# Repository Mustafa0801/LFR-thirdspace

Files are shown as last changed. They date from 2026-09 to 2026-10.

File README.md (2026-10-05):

# LFR-thirdspace
Line following robot project for HackClub YSWS thirdspace, uses 2 motors and an array of 5 sensors

PLEASE NOTE: THE PLAYABLES FOR WEEK 1 AND 2 WERE BUGGED SO I HAVE FIXED THEM NOW, THE LINKS IN THE SUBMISSION DONT WORK SO PLEASE FIND THE DEMOS FOR WEEK 1 AND 2 IN THE PLAYABLES FOLDER

## WEEK 1
It is very important to note that this week we did not really have any of the hardware components for the robot ready e.g motors, sensors, e.t.c.
The only thing we had was the Arduino UNO; it wasn't possible to properly test any of the code so some things in the code have kinda been eyeballed.
Because of that, most of the code at the moment is not finalised and rather the code is more like a first draft.  
For the cad designs, there were a lot of linux glitches, along with save files being corrupted which meant things had to be redone.
The basic things are done but the design will be finalized before 3D printing

## WEEK 2
Had a lot of technical difficulties this week as well in obtaining the parts, and even after we got the parts, some were faulty. 
Also were unable to get chassis printed so only made a very rough version of the robot.  
Due to lack of time we weren't able to test it enough so it has many issues, only motors were tested which aren't working as intended.
However it is probably issue with the hardware rather than the code.

## WEEK 3
Hoped to finish the project this week but once again faced some technical difficulties, did everything that we needed to do however some components seem to be faulty due to which the robot is unable to move. Unfortunately we will have to continue it to the next week. it's very disappointing but it feels there is nothing we can do to make it work.

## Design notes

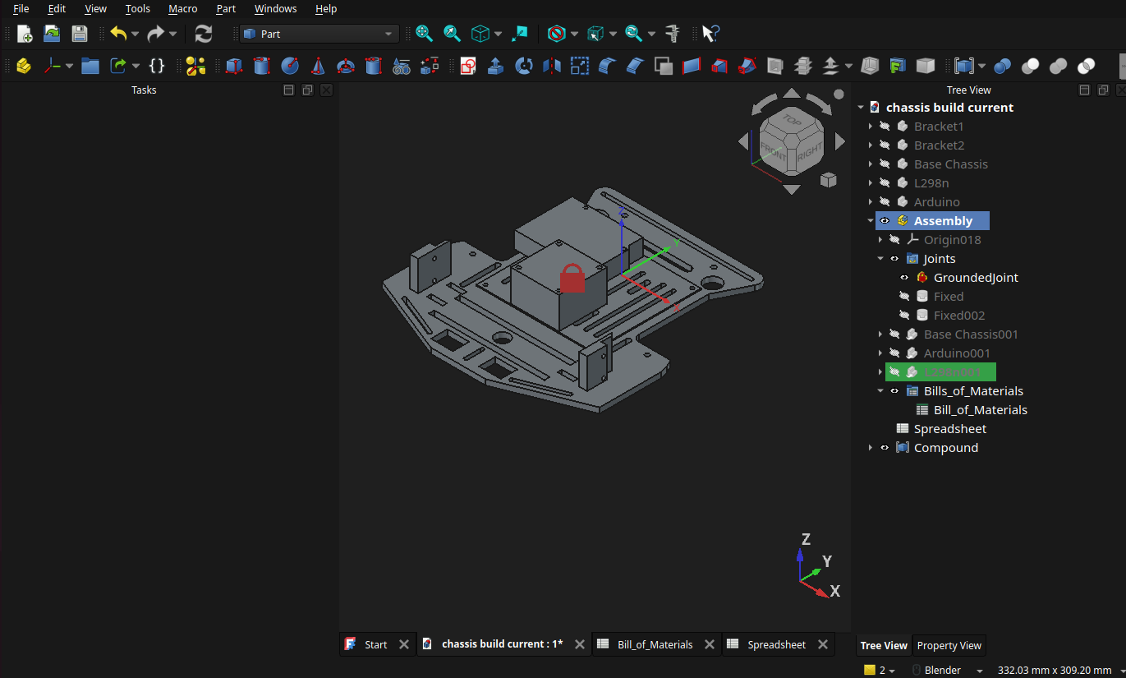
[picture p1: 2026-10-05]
final ship/Screenshot from 2026-10-04 20-36-11.png

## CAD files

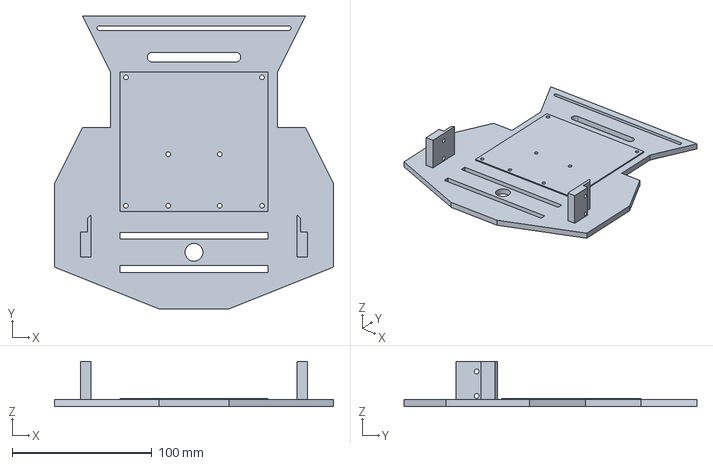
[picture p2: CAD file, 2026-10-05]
final ship/chassis build current with l298n holes and full chassis stuff including 2 chamfer.FCStd
200.0 x 210.0 x 32.5 mm

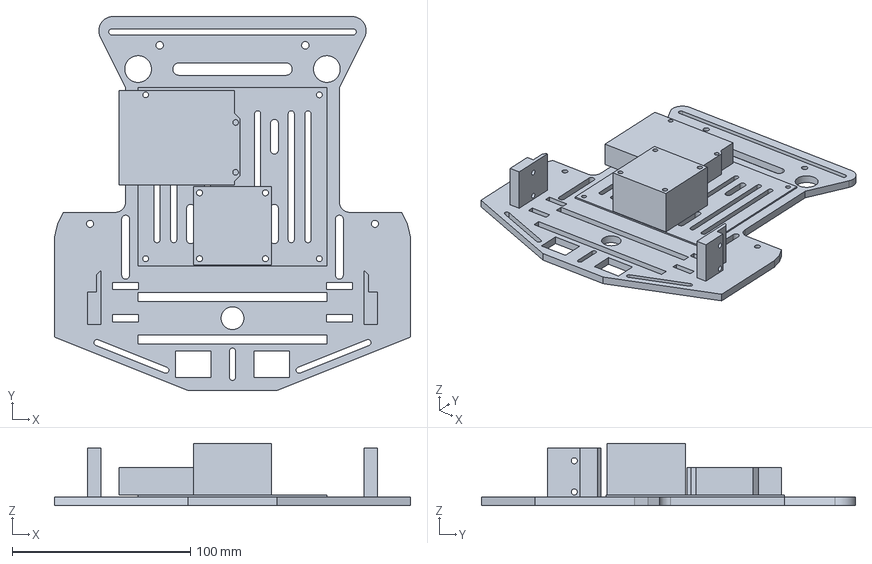
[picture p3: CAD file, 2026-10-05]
final ship/CHASSIS BUILD LAST COMPLETE SENT FOR 3d PR.FCStd
200.0 x 210.0 x 35.0 mm

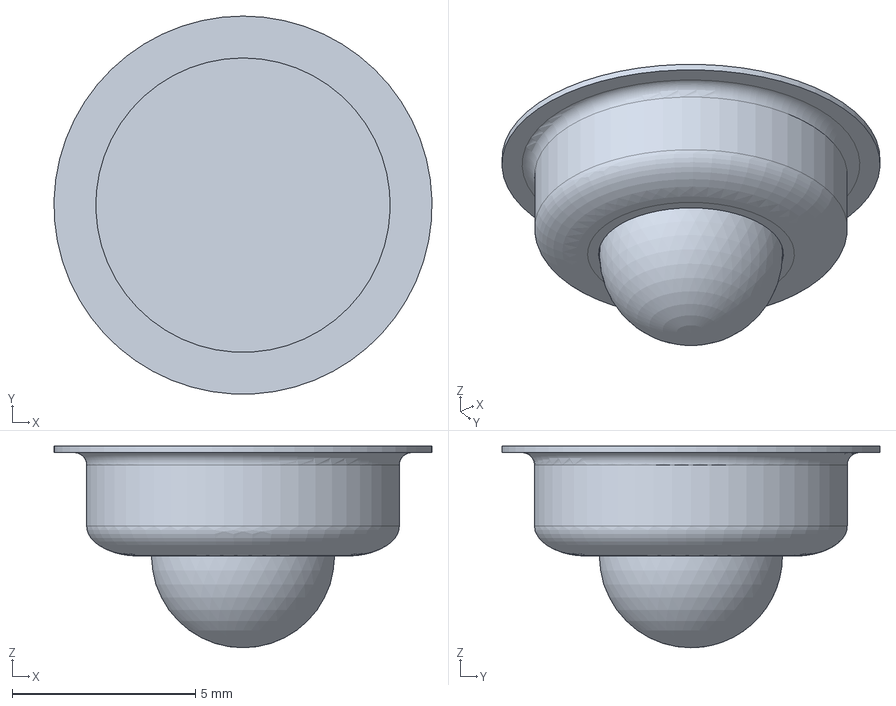
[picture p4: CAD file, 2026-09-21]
CAD files/Final Assembly assorted.FCStd
10.3 x 10.3 x 5.50 mm

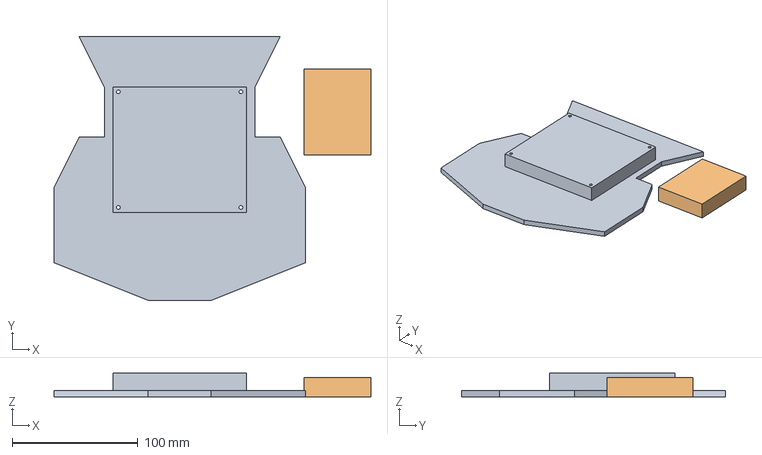
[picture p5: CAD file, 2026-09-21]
CAD files/Unnamed2.FCStd
252.3 x 210.0 x 19.0 mm
Base Chassis
Arduino Dimensions

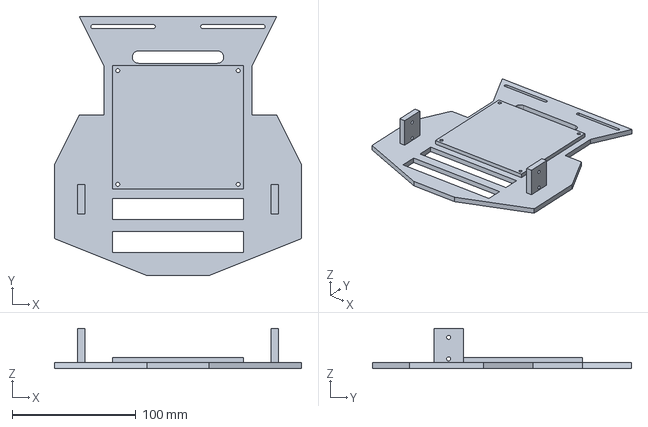
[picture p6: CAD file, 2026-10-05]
final ship/chassis build with hole for wires final.FCStd
200.0 x 210.0 x 32.5 mm

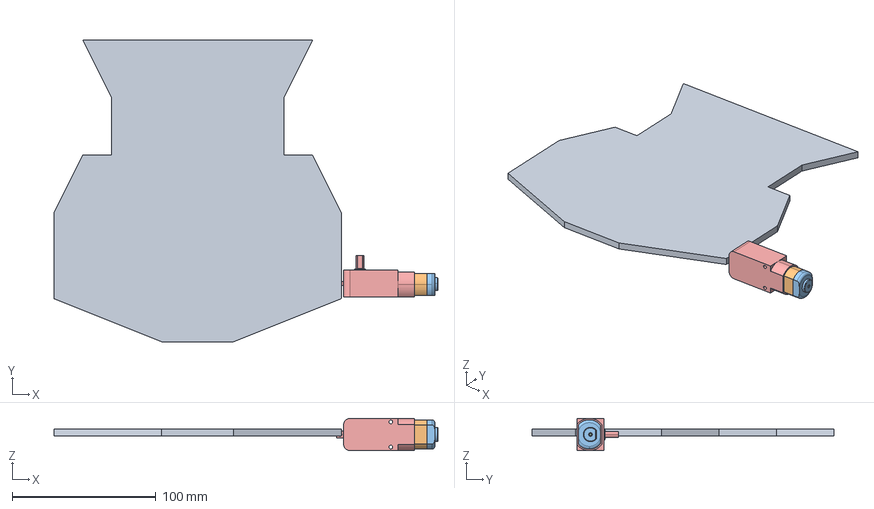
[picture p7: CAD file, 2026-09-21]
CAD files/Base Model One Chassis.FCStd
267.3 x 210.0 x 22.5 mm
Base Chassis
Motor con reductor
Motor con reductor001
Motor con reductor002
Motor con reductor003

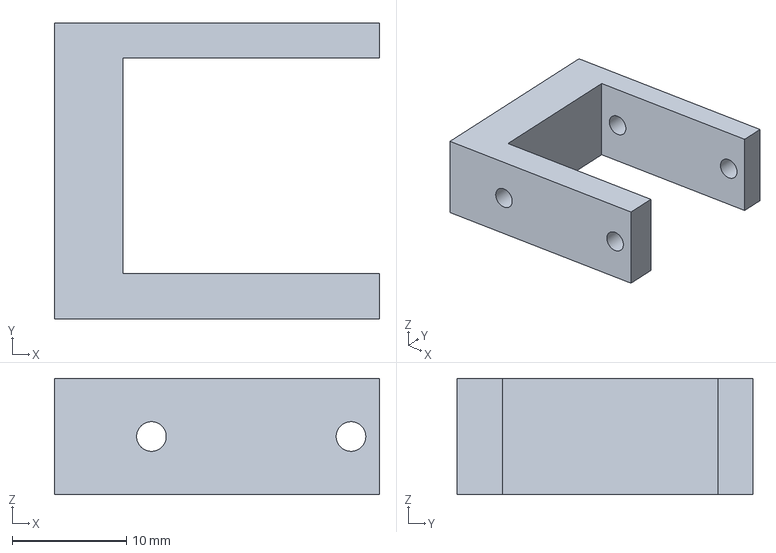
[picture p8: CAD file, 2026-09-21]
CAD files/Bracket for Motor.FCStd
28.5 x 26.0 x 10.2 mm

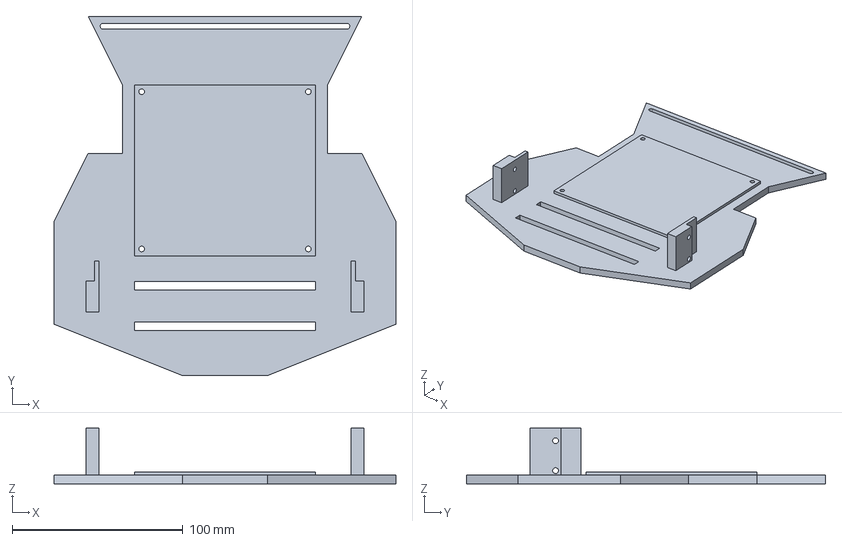
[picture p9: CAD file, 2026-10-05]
final ship/chassis build october 3 proper sensor mount hole 3.35 mm.FCStd
200.0 x 210.0 x 32.5 mm

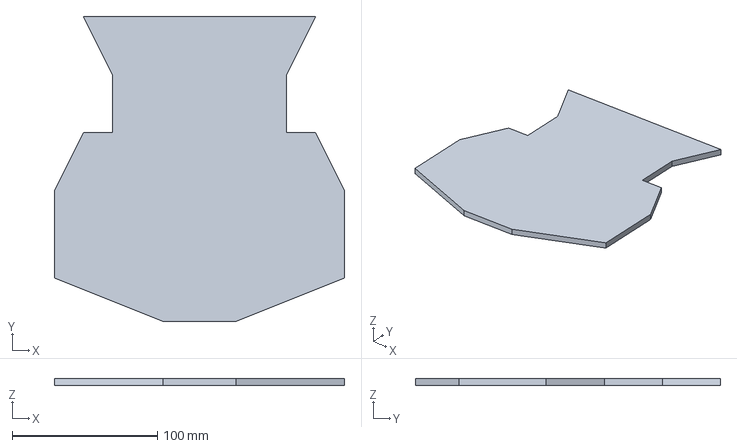
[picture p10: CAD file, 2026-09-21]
CAD files/Base Model One Chassis (Copy).FCStd
200.0 x 210.0 x 5.00 mm

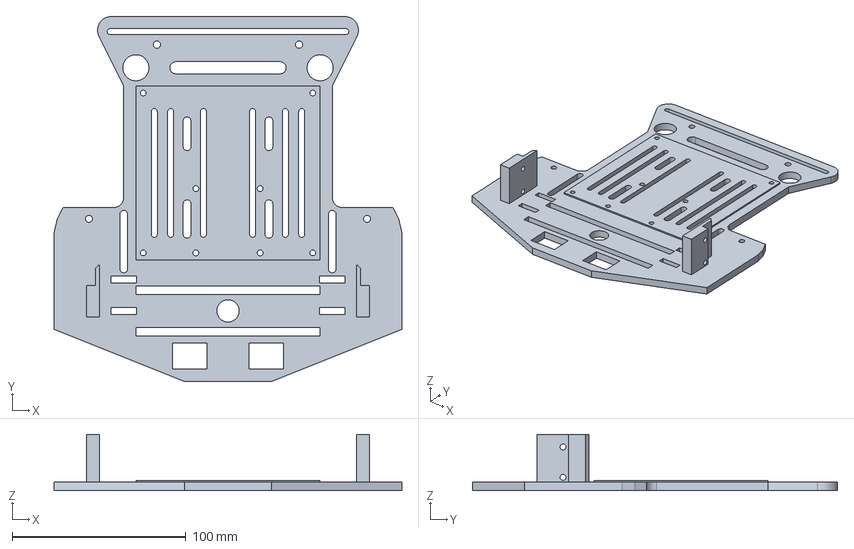
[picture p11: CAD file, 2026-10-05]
final ship/chassis build october 4 with many holes except bottom sensors.FCStd
200.0 x 210.0 x 32.5 mm

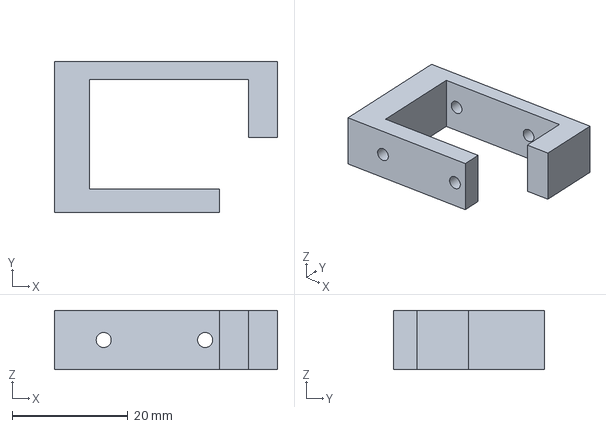
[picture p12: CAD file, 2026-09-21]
CAD files/Bracket for Motor (Copy).FCStd
38.5 x 26.0 x 10.2 mm

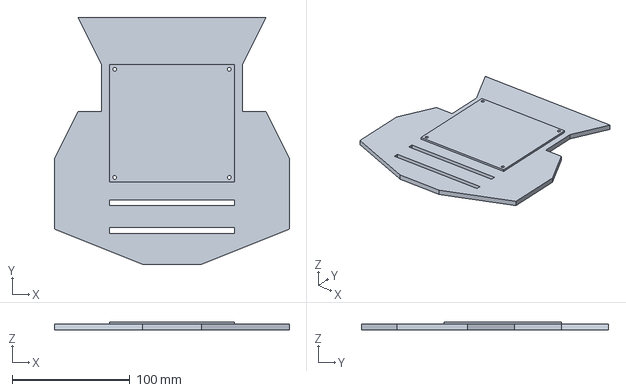
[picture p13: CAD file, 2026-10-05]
final ship/chassis build redone with smaller holes on account of the motor driver.FCStd
200.0 x 210.0 x 7.00 mm

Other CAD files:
CAD files/Assembly retry.FCStd
CAD files/Final Assembly assorted (Copy 2).FCStd
CAD files/Final Assembly assorted (Copy 3).FCStd
CAD files/Final Assembly assorted (Copy).FCStd
CAD files/Final Assembly assorted (Copy 4).FCStd
CAD files/fusionassemblywithball.FCStd
CAD files/Assorted Assets (Copy 3).FCStd
CAD files/Assorted Assets (Copy).FCStd
CAD files/Assorted fusion.FCStd
CAD files/FINAL bracket for motor.FCStd
CAD files/Fused Motor.FCStd
CAD files/Raised platform for arduino.FCStd
CAD files/Unnamed.FCStd
CAD files/fusion1.FCStd
CAD files/mule.FCStd
CAD files/mule2.FCStd
CAD files/sensor hanging mounting bracket.FCStd
final ship/chassis build current.FCStd
final ship/chassis build october 3 first space-saving cut.FCStd
final ship/chassis build october 3 proper bracket hole with indent.FCStd
final ship/chassis build october 3 with proper sensor mount and hole for cables.FCStd

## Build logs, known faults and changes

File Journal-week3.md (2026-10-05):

# Week 3 Hardware Journal
## Mustafa0801
MONDAY --- First I tested motors more and found that the issue was related to power, so I connected more batteries.  
TUESDAY --- Then tested the sensors a bit, found that they need to be quite low to the ground to detect the line.  
FRIDAY --- Wired the buck to the robot, then tested the draft1 of full code on the track, the movement was a bit jittery and the robot was getting stuck.  
SATURDAY --- Moved the track to the floor instead of the bed and tested again, robot was working fine (aside from the movement being a bit snappy)
however the track itself was still causing issues.  
SUNDAY --- Remade the track on the floor, then tested robot a bit on it. Now the issue wasn't the track rather the robot's structure causing it to get stuck.
Then assembled 3D printed chassis and rewired everything, however the robot was still getting stuck on the ground. It would work fine in the air but on the ground the wheels would just not move, which seemed to be a power issue. Even at max speed the robot couldn't move unless it was constantly pushed a little here and there. Could also be due to faulty motors which is something we may not be able to fix now.
    
WhatsApp Image 2026-10-05 at 7 28 50 AM
WhatsApp Image 2026-10-05 at 7 28 49 AM
WhatsApp Image 2026-10-05 at 7 28 51 AM

## Muhammad
Cad journal:
Main things that I did were to make sure all my mounts were proper. It took quite some time and I had to redo them twice or thrice because i realised that either the hole sizes were weird or that my sketch wasnt truly editable or changable later, and so for the sake of making possible edits i redid many sketches on the base plate
I also calculated the volume requires to 3d print the base chassis in the BOM, ans generally just validated my design
I also added a small modular plate thing on the padded area at the top and added mounting holes and weights to the arduino and l298n. Freecad crashed and my files corrupted twice so I had to redo them again. Lastly i imported my model to make sure it sliced properly in the prussa slicer. It did, so I tried to find the center of mass with the weights so I couls find the optimum place to put in the "castor wheel"  (but it didnt end up working properly so I just eyeballed it and called it a day)

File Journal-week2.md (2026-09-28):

# Week 2 Hardware Journal 
## Mustafa0801
Created a track for the LFR, by putting black tape on a white sheet. (took about 2 hours)  
Then tested the robot with the motor code, adjusted some wiring and components on the robot and updated code accordingly. (about 5 hours)
However motors still didnt work as intended, most times when both should move only 1 moves or neither move, probably a power issue.  
  \
WhatsApp Image 2026-09-28 at 6 55 17 AM
WhatsApp Image 2026-09-28 at 6 55 18 AM
WhatsApp Image 2026-09-28 at 6 56 11 AM

## Muhammad
Took a lot of time wiring the robot, motors kept falling off so they had to be re-adjusted. Lengths were measured for the base.

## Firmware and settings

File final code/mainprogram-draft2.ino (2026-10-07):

// INCORPORATNG EVERYTHING INCLUDING PID, THIS WILL PROBABLY BE FINAL CODE (AFTER TESTING)

// pin numbers for motors and wheel servos

#define leftMotor 5
#define rightMotor 3
#define lf 2    // left forward servo
#define rf 7    // right forward servo
#define lb 4    // left back servo
#define rb 6    // right back servo

// pin numbers for sensor array

#define irL2 8   // left most
#define irL1 9  // left of middle
#define irM 10    // middle
#define irR1 11    // right of middle
#define irR2 12    // right most

float error;
float previousError = 0;    
float integral = 0;

float baseSpeed = 200.0;  
float leftSpeed;
float rightSpeed;

unsigned long currentTime;    // used to calculate delta time
unsigned long lastTime;

float Kp = 20.0;
float Ki = 0.5;    // constants used to calculate PID (still need to be adjusted) 
float Kd = 5.0;

void setup() {
  pinMode(leftMotor, OUTPUT);
  pinMode(rightMotor, OUTPUT);
  pinMode(lf, OUTPUT);
  pinMode(rf, OUTPUT);
  pinMode(lb, OUTPUT);
  pinMode(rb, OUTPUT);

  pinMode(irL2, INPUT);
  pinMode(irL1, INPUT);
  pinMode(irM, INPUT);
  pinMode(irR1, INPUT);
  pinMode(irR2, INPUT);

  lastTime = micros();
  Serial.begin(9600);
}

void loop() {
  error = ReadSensors();
  float outputPID = CalculatePID(error);

  Serial.println();

  leftSpeed = baseSpeed - outputPID;
  rightSpeed = baseSpeed + outputPID;  // speed is adjusted according to PID to allow robot to move smoothly and accurately

  // maximum and minimum thresholds for speed, since we can only analogWrite values between 0-255 inclusive
  if (leftSpeed > 255.0){
    leftSpeed = 255.0;
  }
  else if (leftSpeed < 0){
    leftSpeed = 0;
  }
  if (rightSpeed > 255.0){
    rightSpeed = 255.0;
  }
  else if (rightSpeed < 0){
    rightSpeed = 0;
  }

  leftSpeed = round(leftSpeed);     // converting speeds from float to int since the movement functions need integer value for speed
  rightSpeed = round(rightSpeed);
  Serial.print(" | left speed: "+String(leftSpeed)+" right speed: "+String(rightSpeed));

  Forward(leftSpeed, rightSpeed);  // the direction will be automatically changed by the varying left and right speeds

  Serial.println();   // going to next line
}

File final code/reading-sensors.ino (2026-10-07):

//  FUNCTION FOR READING SENSORS AND CALCULATING ERROR FROM LINE

float ReadSensors(){
  int _readingL2 = !digitalRead(irL2);
  int _readingL1 = !digitalRead(irL1);
  int _readingM = !digitalRead(irM);    // reading all sensors, 
  int _readingR1 = !digitalRead(irR1);  // ! inverts the values since the formula for calculating error assumes that a sensor detecting the line gives value 1
  int _readingR2 = !digitalRead(irR2);

  Serial.print("Readings: "+String(_readingL2)+" "+String(_readingL1)+" "+String(_readingM)+" "+String(_readingR1)+" "+String(_readingR2)); // prints readings in a line e.g  0 1 0 0 0

  if ((_readingL2 + _readingL1 +_readingM + _readingR1 + _readingR2) == 0){ // prevents dividing by zero in weight position formula
    return previousError;
  }

  // weighted position algorithm to calculate error

  float _currentPosition = (_readingL2*0 + _readingL1*1 + _readingM*2 + _readingR1*3 + _readingR2*4) / (_readingL2 + _readingL1 + _readingM + _readingR1 + _readingR2);
  float _normalPosition = 2.0;
  float _error = _normalPosition - _currentPosition;  // negative error means robot is right side of line (needs to move left), 
                                                      // positive error means robot is left side of line (needs to move right)

  // value of _currentPosition will be between 0 and 4.0 inclusive, hence value of _error will be between -2.0 and 2.0 inclusive
                              
  Serial.print(" | error: "+String(_error));
  return _error;
}

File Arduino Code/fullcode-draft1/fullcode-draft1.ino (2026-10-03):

//  COMBINING PREVIOUS WRITTEN CODE INTO ONE FILE TO GET A DRAFT OF THE COLLECTIVE CODE

#define leftMotor 5
#define rightMotor 3
#define lf 2  // declaring pin numbers for motors
#define lb 4
#define rf 7
#define rb 6

#define irL2 8 // declaring pin numbers for sensor array
#define irL1 9
#define irM 10
#define irR1 11
#define irR2 12

int leftSpeed = 200;  // placeholder values for speeds
int rightSpeed = 200;
int linePos;

void setup() {
  pinMode(leftMotor, OUTPUT);
  pinMode(rightMotor, OUTPUT);
  pinMode(lf, OUTPUT);
  pinMode(lb, OUTPUT);    
  pinMode(rf, OUTPUT);
  pinMode(rb, OUTPUT);

  pinMode(irL2, INPUT);
  pinMode(irL1, INPUT);
  pinMode(irM, INPUT);
  pinMode(irR1, INPUT);
  pinMode(irR2, INPUT);

  Serial.begin(9600);
}

void loop() {
  linePos = ReadSensors();  // reads all sensors, prints in serial, and stores line position

  switch (linePos){     // checks line position to decide movement of robot
    case -4:            
      leftRotate(leftSpeed, rightSpeed);  // if line is far left then robot needs to turn sharply left
      break;
    case -2:
      leftTurn(leftSpeed, rightSpeed);      // line is slightly left so robot needs to move left slightly
      break;
    case 0:
      forward(leftSpeed, rightSpeed);   // line is infront so robot needs to move forward
      break;
    case 2:
      rightTurn(leftSpeed, rightSpeed);     // line slightly right, robot needs to move slightly right
      break;
    case 4:
      rightRotate(leftSpeed, rightSpeed); // line far right, robot needs to turn sharply right
      break;
  }

  Serial.println();   // goes to next line in serial
}

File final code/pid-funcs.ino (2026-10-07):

// FUNCTIONS FOR CALCULATING DELTA TIME AND CALCULATING PID

float CalculateDeltaTime(){
  currentTime = micros();   // total time since start
  float _dt = (currentTime - lastTime) / 1000000.0;   // difference in time between each loop, converted to seconds
  lastTime = currentTime;   // last time updated for next loop
  Serial.print(" | dt: "+String(_dt));

  return _dt; 
}

float CalculatePID(float _error){
  float deltaTime = CalculateDeltaTime();
  float _output;

  if (deltaTime <= 0){  // to prevent dividing by zero
    _output = 0;
  }
  else{
    integral = integral + (_error * deltaTime);   // sums errors over time
    float _derivative = (_error - previousError) / deltaTime;   // rate of change of errors

    previousError = _error;   // previous error updated for next loop

    _output = (Kp * _error) + (Ki * integral) + (Kd * _derivative); // calculating PID output

    // limits output to prevent integral windup, NOTE: speeds can still exceed max and min values with this so they also need to be limited seperately
    if (_output > 255.0){
      _output = 255.0;
      integral = integral - (_error * deltaTime);  // prevents integral from further accumulating
    }
    else if (_output < -255.0){
      _output = -255.0;
      integral = integral - (_error * deltaTime);  // prevents integral from further accumulating
    }
  }
  Serial.print(" | PID output: "+String(_output));
  return _output;
}

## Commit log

2026-09-16 fix sensor test code and rename
    [sensor-test.ino]
2026-09-17 add file to folder and update sensor test code
2026-09-17 Add sensor function file
    this contains function that prints sensor reading in serial monitor
2026-09-17 Add motor test code files
    These files contain the code for the functions of the movement of the robot and tests each function
2026-09-19 update speed adjustment code
    added min and max thresholds for speed, also made it so that line position has greater chance to be 0 to make it closer to how the actual sensors will be together with the full robot
2026-09-20 Add new line in other ideas
    Add line regarding making a PID algorithm
2026-09-20 Add pid algo files
2026-09-20 Add file containing PID calculating function
2026-09-20 update with serial message for error
    [sensor-reading.ino]
2026-09-20 Add serial message for PID output
2026-09-20 update code to prevent delta time being zero
    [PID-calculator.ino]
2026-09-20 edit functions to have seperate speed for both motors
2026-09-20 edit to have seperate speeds for both motors
2026-09-21 Create CAD files folder
2026-09-21 Add cad files to folder
    [Assembly retry.FCStd, Assorted Assets (Copy 3).FCStd, Assorted Assets (Copy).FCStd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]
2026-09-25 change pin numbers
2026-09-25 edit pin numbers
2026-09-27 upload sensor reading func (unfinished)
2026-09-27 Add pid calculating file (unfinished)
2026-09-27 fix mistake with selection statement
    [mainprogram-draft2.ino]
2026-09-27 fix mistake with error calculation
    [reading-sensors.ino]
2026-09-27 fixed mistake
    conditions were comparing float number with integer numbers
    [mainprogram-draft2.ino]
2026-09-27 update code
    add check to limit output and prevent integral windup, also update comments
    [pid-funcs.ino]
2026-09-27 update code
    change movement functions since robot ended up having two wheels instead of four
2026-09-27 fix pin number
    previous pin number wasnt PWM so analog write wouldnt work on it
    [motor-test.ino]
2026-09-27 revert functions to normal with slight update
    the previous edits i made were wrong and after changing the hardware i actually needed to use the original functions
    [movement-functions.ino]
2026-09-27 Revert code
    after changing wiring on robot, actually needed to use the original way with 6 pins being used
    [motor-test.ino]
2026-09-27 revert pin numbers back
    change wiring again so original pin numbers
    [sensor-test.ino]
2026-09-27 update code after changing wiring
2026-09-28 Rename WhatsApp Video 2026-09-28 at 6.55.20 AM.mp4 to week 2 motors demo.mp4
2026-10-01 Revert code after debugging
    [motor-test.ino]
2026-10-01 add kickstart speed which is later decreased
    testing at which speeds wheels turn properly
2026-10-01 Add comment
    tested different speeds and added comment for the minimum speed needed for wheels to move properly otherwise they get stuck
    [motor-test.ino]
2026-10-03 change case statement according to new functions
2026-10-05 Add final ship files
    [CHASSIS BUILD LAST COMPLETE SENT FOR 3d PR.FCStd, chassis build current with l298n holes and full chassis stuff including 2 chamfer.FCStd, chassis build curren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]
2026-10-07 update code
    prevents dividing by zero if dt is zero
    [pid-funcs.ino]
2026-10-07 update code
    fixed so that it works properly with error calculating formula
    [reading-sensors.ino]
2026-10-11 change value of constants
    Adjusted PID constants for better control tuning.
2026-10-11 edit for analogue sensors
2026-10-11 fix pin number
2026-10-11 update code
    allows motors to reverse when speeds negative
2026-10-11 change value of constants
    Adjusted PID constants Kp and Kd for tuning.
